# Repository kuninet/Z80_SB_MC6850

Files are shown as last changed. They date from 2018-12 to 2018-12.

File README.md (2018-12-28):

# Z80_SB_MC6850

## 概要
- Z80 CPUを搭載した シングルボードコンピューターです。シリアルチップは MC6850です。
  - 以下のGrrant氏の回路図を参考に、SBC8080バスへ接続できるように改良したものとなります。
  - http://searle.hostei.com/grant/z80/SimpleZ80_32K.html

## 回路図

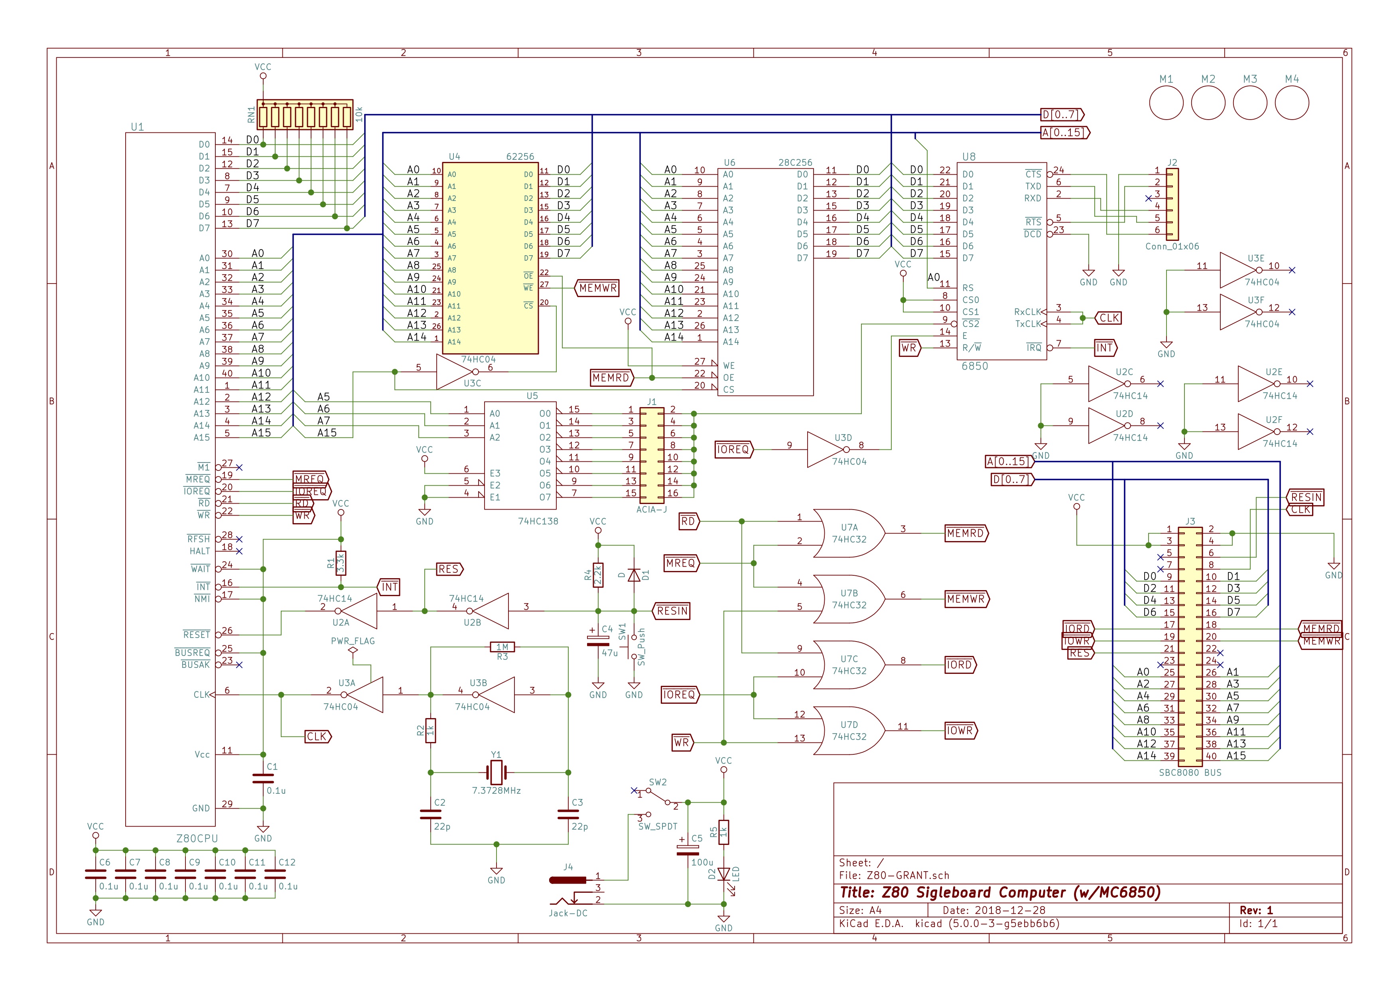
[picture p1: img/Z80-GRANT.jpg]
回路図


## 部品表
- 部品表は以下にあります。
  - [https://github.com/kuninet/Z80_SB_MC6850/blob/master/KiCAD/Z80-GRANT.ods](https://github.com/kuninet/Z80_SB_MC6850/blob/master/KiCAD/Z80-GRANT.ods)

## 注意点
- ★本基板は試作して確認中のため不具合を含んでいる可能性があります。

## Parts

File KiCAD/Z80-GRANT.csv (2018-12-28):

部品番号 | 仕様 | 数量 | 代替部品 | Footprint
U1 | Z84C0020PEC | 1 | Z80 CPU | Housings_DIP:DIP-40_W15.24mm_Socket
U2 | 74HC14 | 1 | 74HCT14 | Housings_DIP:DIP-14_W7.62mm_Socket
U3 | 74HC04 | 1 | 74HCT04、74HCU04 | Housings_DIP:DIP-14_W7.62mm_Socket
U4 | 62256型SRAM | 1 |  | Housings_DIP:DIP-28_W15.24mm_Socket
U5 | 74HC138 | 1 | 74HCT138 | Housings_DIP:DIP-16_W7.62mm_Socket
U6 | 28C256型EEPROM | 1 |  | Housings_DIP:DIP-28_W15.24mm_Socket
U7 | 74HC32 | 1 | 75HCT32 | Housings_DIP:DIP-14_W7.62mm_Socket
U8 | MC6850 | 1 |  | Housings_DIP:DIP-24_W15.24mm_Socket
R1 | 3.3k | 1 | 1/4W カーボン抵抗器 | Resistors_THT:R_Axial_DIN0207_L6.3mm_D2.5mm_P10.16mm_Horizontal
R2、R5 | 1kΩ | 1 | 1/4W カーボン抵抗器 | Resistors_THT:R_Axial_DIN0207_L6.3mm_D2.5mm_P10.16mm_Horizontal
R3 | 1MΩ | 1 | 1/4W カーボン抵抗器 | Resistors_THT:R_Axial_DIN0207_L6.3mm_D2.5mm_P10.16mm_Horizontal
R4 | 2.2kΩ | 1 | 1/4W カーボン抵抗器 | Resistors_THT:R_Axial_DIN0207_L6.3mm_D2.5mm_P10.16mm_Horizontal
Y1 | 7.3728MHz | 1 | 水晶振動子 | Crystals:HC-49V
C1、C6〜C12 | 0.1u | 8 | 積層セラミックコンデンサ | Capacitors_THT:C_Disc_D3.0mm_W2.0mm_P2.50mm
C2、C3 | 22pF | 2 | 積層セラミックコンデンサ | Capacitors_THT:C_Disc_D3.0mm_W2.0mm_P2.50mm
C4 | 47uF | 1 | 電解コンデンサ | Capacitors_THT:CP_Radial_D4.0mm_P1.50mm
C5 | 100uF | 1 | 電解コンデンサ | Capacitors_THT:CP_Radial_D8.0mm_P2.50mm
SW1 | タクトスイッチ | 1 | リセット用タクトスイッチ | Buttons_Switches_THT:SW_PUSH_6mm
J1 | 2列x8 ピンヘッダ | 1 |  | Pin_Headers:Pin_Header_Straight_2x08
J2 | 01x06 L型ピンヘッダ | 1 |  | Pin_Headers:Pin_Header_Angled_1x06
J3 | 40pinL型ボックスヘッダ | 1 | 2x20 L型ピンヘッダ | Pin_Headers:Pin_Header_Angled_2x20
J4 | MJ-179PH | 1 | 同型のDCジャック同等品 | Connectors:BARREL_JACK
SW2 | 基板実装用スライドスイッチ | 1 |  | digikey-footprints:Switch_Slide_11.6x4mm_EG1218
RN1 | 10kΩ集合抵抗器 | 1 | 9pin 集合抵抗器 10k | Resistors_THT:R_Array_SIP9
D1 | 1S1588 | 1 | 小電力ダイオード | Diodes_THT:D_A-405_P7.62mm_Horizontal
D2 | LED | 1 | 3mm LED | LEDs:LED_D3.0mm

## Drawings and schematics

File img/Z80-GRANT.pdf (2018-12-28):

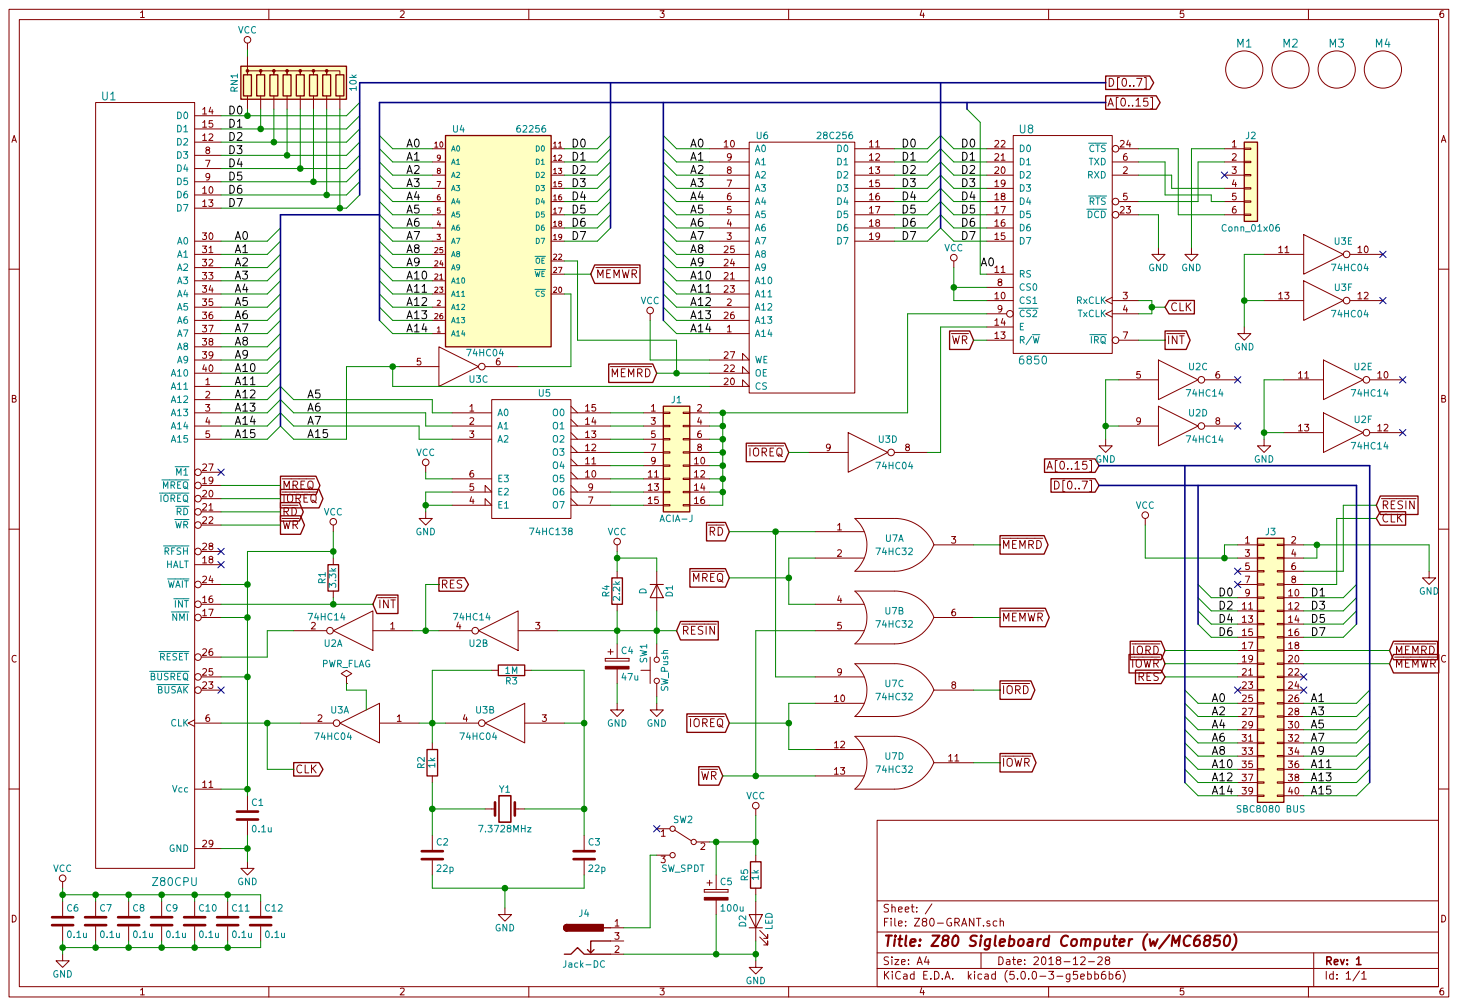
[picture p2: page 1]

9 | 10
11 | 12
13 | 14

Id: 1/1 Title: Z80 Sigleboard Computer (w/MC6850) File: Z80-GRANT.sch Sheet: /

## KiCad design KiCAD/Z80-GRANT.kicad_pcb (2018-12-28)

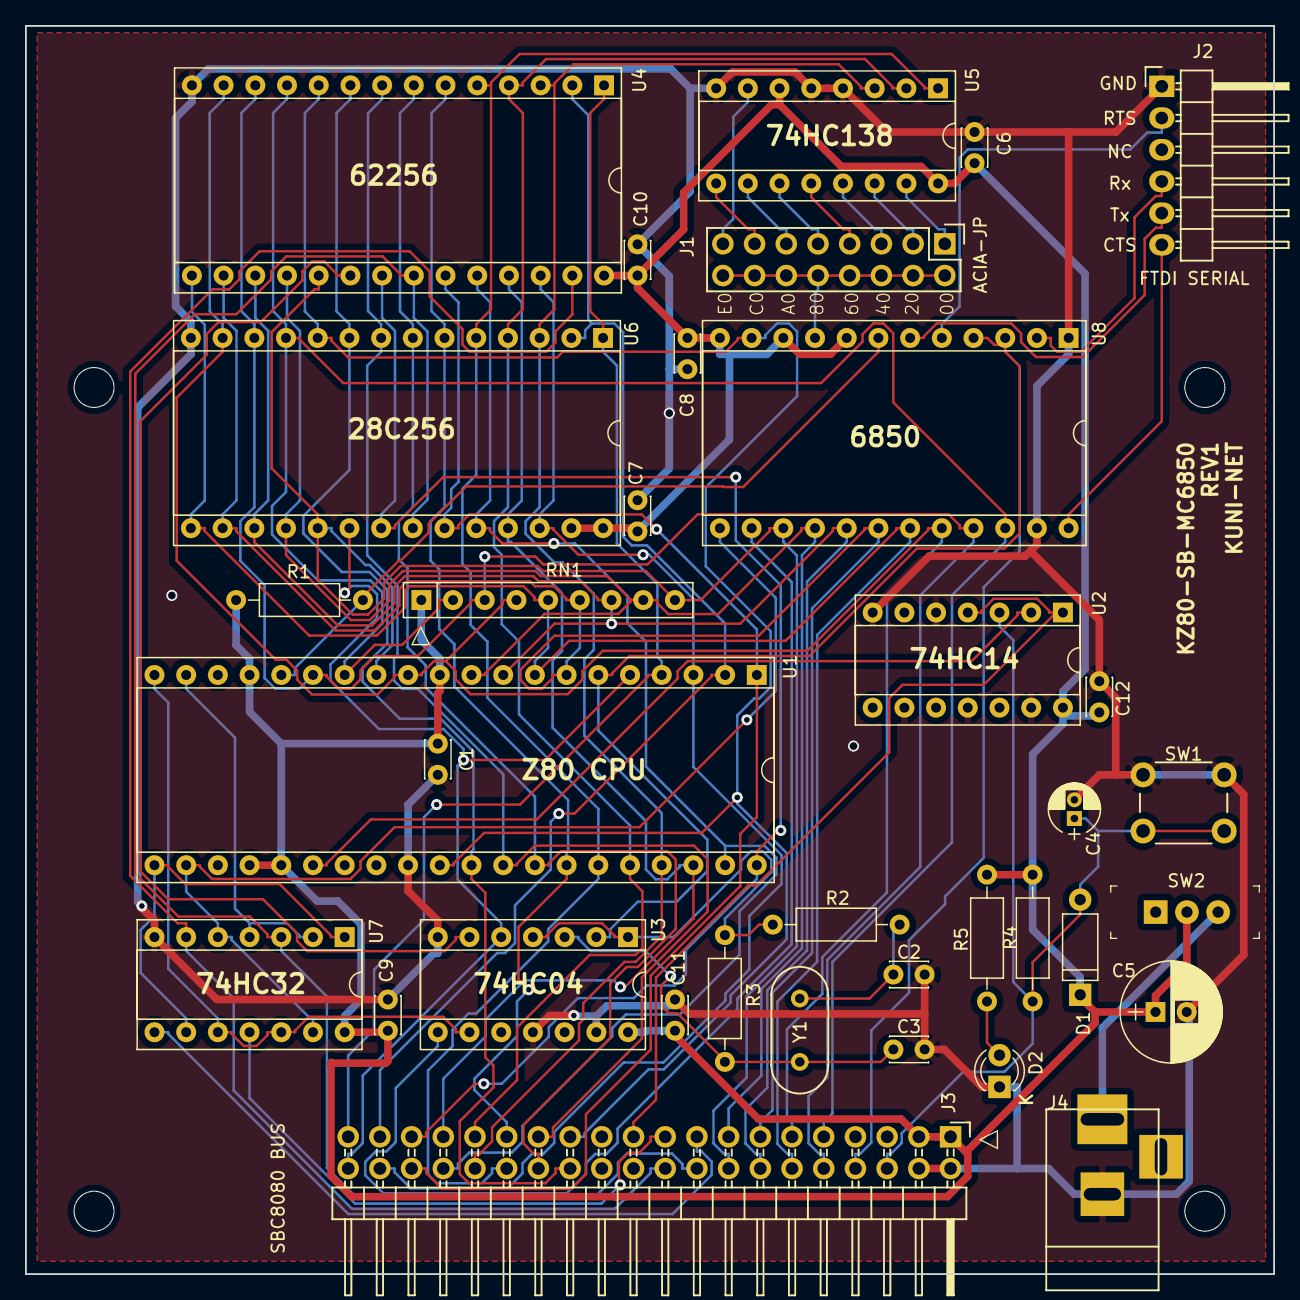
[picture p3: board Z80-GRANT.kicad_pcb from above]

Board: 2 copper layers, 100.0 x 100.0 mm, 39 parts (0 on the bottom side), 59 nets.

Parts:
C1, C6, C7, C8, C9, C10, C11, C12: 0.1u; C_Disc_D3.0mm_W2.0mm_P2.50mm
C2, C3: 22p; C_Disc_D3.0mm_W2.0mm_P2.50mm
C4: 47u; CP_Radial_D4.0mm_P1.50mm
C5: 100u; CP_Radial_D8.0mm_P2.50mm
D1: D; D_A-405_P7.62mm_Horizontal
D2: LED; LED_D3.0mm
J1: ACIA-J; Pin_Header_Straight_2x08
J2: Conn_01x06; Pin_Header_Angled_1x06
J3: SBC8080 BUS; Pin_Header_Angled_2x20
J4: Jack-DC; BARREL_JACK
M1, M2, M3, M4: MountingHole_M3; MountingHole_3.2mm_M3
R1: 3.3k; R_Axial_DIN0207_L6.3mm_D2.5mm_P10.16mm_Horizontal
R2, R5: 1k; R_Axial_DIN0207_L6.3mm_D2.5mm_P10.16mm_Horizontal
R3: 1M; R_Axial_DIN0207_L6.3mm_D2.5mm_P10.16mm_Horizontal
R4: 2.2k; R_Axial_DIN0207_L6.3mm_D2.5mm_P10.16mm_Horizontal
RN1: R_Network08; R_Array_SIP9
SW1: SW_Push; SW_PUSH_6mm
SW2: SW_SPDT; Switch_Slide_11.6x4mm_EG1218
U1: Z80CPU; DIP-40_W15.24mm_Socket
U2: 74HC14; DIP-14_W7.62mm_Socket
U3: 74HC04; DIP-14_W7.62mm_Socket
U4: 62256; DIP-28_W15.24mm_Socket
U5: 74LS138; DIP-16_W7.62mm_Socket
U6: 28C256; DIP-28_W15.24mm_Socket
U7: 74LS32; DIP-14_W7.62mm_Socket
U8: 6850; DIP-24_W15.24mm_Socket
Y1: Crystal; HC-49V

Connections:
A0: J3.25, U1.30, U4.10, U6.10, U8.11
A1: J3.26, U1.31, U4.9, U6.9
A2: J3.27, U1.32, U4.8, U6.8
A3: J3.28, U1.33, U4.7, U6.7
A4: J3.29, U1.34, U4.6, U6.6
A5: J3.30, U1.35, U4.5, U5.1, U6.5
A6: J3.31, U1.36, U4.4, U5.2, U6.4
A7: J3.32, U1.37, U4.3, U5.3, U6.3
A8: J3.33, U1.38, U4.25, U6.25
A9: J3.34, U1.39, U4.24, U6.24
A10: J3.35, U1.40, U4.21, U6.21
A11: J3.36, U1.1, U4.23, U6.23
A12: J3.37, U1.2, U4.2, U6.2
A13: J3.38, U1.3, U4.26, U6.26
A14: J3.39, U1.4, U4.1, U6.1
A15: J3.40, U1.5, U3.5, U6.20
CLK: J3.8, U1.6, U3.2, U8.3, U8.4
D0: J3.9, RN1.2, U1.14, U4.11, U6.11, U8.22
D1: J3.10, RN1.3, U1.15, U4.12, U6.12, U8.21
D2: J3.11, RN1.4, U1.12, U4.13, U6.13, U8.20
D3: J3.12, RN1.5, U1.8, U4.15, U6.15, U8.19
D4: J3.13, RN1.6, U1.7, U4.16, U6.16, U8.18
D5: J3.14, RN1.7, U1.9, U4.17, U6.17, U8.17
D6: J3.15, RN1.8, U1.10, U4.18, U6.18, U8.16
D7: J3.16, RN1.9, U1.13, U4.19, U6.19, U8.15
GND: C1.2, C2.2, C3.2, C4.2, C5.2, C6.2, C7.2, C8.2, C9.2, C10.2, C11.2, C12.2, D2.1, J2.1, J3.2, J3.4, J4.2, SW1.1, U1.29, U2.5, U2.7, U2.9, U2.11, U2.13, U3.7, U3.11, U3.13, U4.14, U5.4, U5.5, U5.8, U6.14, U7.7, U8.1, U8.23
unnamed: C2.1, R2.1, Y1.1
unnamed: C3.1, R3.1, U3.3, Y1.2
unnamed: D2.2, R5.1
unnamed: J1.1, U5.15
unnamed: J1.3, U5.14
unnamed: J1.5, U5.13
unnamed: J1.7, U5.12
unnamed: J1.9, U5.11
unnamed: J1.2, J1.4, J1.6, J1.8, J1.10, J1.12, J1.14, J1.16, U8.9
unnamed: J1.11, U5.10
unnamed: J1.13, U5.9
unnamed: J1.15, U5.7
unnamed: J2.2, U8.5
unnamed: J2.4, U8.2
unnamed: J2.5, U8.6
unnamed: J2.6, U8.24
unnamed: J4.1, SW2.3
unnamed: R2.2, R3.2, U3.1, U3.4
unnamed: U1.26, U2.2
unnamed: U3.6, U4.20
unnamed: U3.8, U8.14
RES: J3.21, U2.1, U2.4
VCC: C1.1, C5.1, C6.1, C7.1, C8.1, C9.1, C10.1, C11.1, C12.1, D1.1, J3.1, J3.3, R1.2, R4.2, R5.2, RN1.1, SW2.2, U1.11, U1.17, U1.24, U1.25, U2.14, U3.14, U4.28, U5.6, U5.16, U6.27, U6.28, U7.14, U8.8, U8.10, U8.12
~INT: R1.1, U1.16, U8.7
~IORD: J3.17, U7.8
~IOREQ: U1.20, U3.9, U7.10, U7.12
~IOWR: J3.19, U7.11
~MEMRD: J3.18, U4.22, U6.22, U7.3
~MEMWR: J3.20, U4.27, U7.6
~MREQ: U1.19, U7.2, U7.4
~RD: U1.21, U7.1, U7.9
~RESIN: C4.1, D1.2, J3.6, R4.1, SW1.2, U2.3
~WR: U1.22, U7.5, U7.13, U8.13

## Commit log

2018-12-28 init commit
    [Z80-GRANT-2018-09-22-09-24-24.sch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]
2018-12-28 回路図イメージ、部品表追加
    [Z80-GRANT.csv, Z80-GRANT.ods, Z80-GRANT.sch]
